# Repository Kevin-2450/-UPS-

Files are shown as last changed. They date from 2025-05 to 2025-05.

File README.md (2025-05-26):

# 内置电池的SK150C桌面电源

#### 介绍
给自己DIY的内置电池的SK150C桌面电源写的固件。

#### 开源硬件
 https://oshwhub.com/kevin1415926/sk150c-expansion-board-four-stri

## 项目简介
本项目是以STM32F030F4P6作为EC，HUSB238作为协议芯片取电，SC8886S作为充电/电源路径管理芯片，以BM3451作为锂电池保护和均压芯片。虽然是作为SK150C的拓展板来设计的，其实实际上达到了一个UPS电源的效果。
V2版本，相较V1硬件软件都有所改动：
* RY9121更换为RY8411；
* 增加散热风扇，散热风扇尺寸为2507，风扇驱动电压为5V；
* 重建3D外壳减小整体尺寸；
* 侧面引出复位按键；
* 电池组不再绑定在PCB上。另外采用了一个4串一并的21700锂电池组，散热和灵活性更加优秀。

## 项目参数和功能

* 左侧两个C口靠后的是充电口，靠前的一个连接到了CH342K，这个芯片的两个串口，分别连接到EC（COM19）和SK150C（COM15）连接到EC的串口可以读取充放电信息以及适配器信息，连接到SK150C的串口可以连接到SK150C的上位机玩；
* 正面的按键是开关，按下之后SK150C会上电并且按键会亮起；
* 本项目固件中自动使用HUSB238向适配器动态申请最高电压，并且根据适配器输入出电流能力设置输入限流；
* 由SC8886S自动完成电源路径动态管理；
* 实测V2版本在有风扇辅助散热的情况下最大充电功率可以达到100W；
* 两个LED实现简单的充电指示，当充电电流>=0.1A的时候左侧LED常亮表示正在充电，当充电电流<0.1A的时候充电截至（即充满）右侧LED常亮；
* 拔出电源适配器的时候系统进入低功耗模式，单片机本身进入stop模式，暂时没有测低功耗模式续航；
* BM3451电池保护芯片对四节电池进行均压和过充过放过流保护；
* 外壳在两个C口边上留了复位按键的小孔，在出现意外的错误的时候可以复位主控。

## 软件代码
代码请移步：
gitee地址：https://gitee.com/Xiao_Hang123/UPS_SC8886S_STM32F030.git
github地址https://github.com/Kevin-2450/-UPS-.git
模型文件一并保存在这个项目中，使用catia画的

## 注意事项

* 电源芯片SC8886和SC8886S不能在这里混用，用SC8886会导致DCDC电路震荡，需要修改RC补偿网络我尝试过几组值但是没有成功.
* PCB上R12是NTC电阻，需要10KB值为3950的热敏电阻，如果不需要温度保护功能则在PCB正面R12的地方焊一个10K的电阻，如果需要温度保护功能则正面的R12留空，背面有NTC电阻的焊盘在那里焊上NTC电阻然后把NTC电阻贴到电池组上；
* 电池刚装上去或者电池拆下来又装上去之后BM3451会进入保护状态，需要先插入STlink给单片机供电然后插入电源适配器进入一下充电状态激活电池组。拔下stlink之后再次插入适配器如果充电指示灯正常亮起那么应该正常激活了

## 组装流程
* PCB装之前需要激活电池（BM3451初始状态时保护的，需要充一下电激活），不建议用另一个可调电源绕过sc8886直接给电池组充电，有概率击穿buck boost电路的MOSFET。
* 先装两个香蕉插头和按钮，然后先把香蕉插头和按钮背面的线先接好，按钮需要先焊线，需要一个单头的XH2.54- 4P的线，原理图上对应的按键接口中，VOUT和PGND连接到按钮的LED两个引脚（注意是有极性的），KEY和AGND连接到按钮的一组常开触点上，按键的插口在靠近输出的那个XT30接口的位置；
* PCB上另一个xh2.54-4P的针座和SK250C背后的串口接口相连，需要xh2.54-4P的同向双头线，长度10cm左右即可
* 接线示意图：




* 风扇应该用四个M2.5的螺丝固定上去，但是手头没有就直接热熔胶打上去了
* 里面的螺母不好上，可以先用热熔胶固定到指定位置然后直接拧上螺丝

## 一些物料购买链接
   购买链接仅供参考
* SK150C本体：【淘宝】7天无理由退货 https://e.tb.cn/h.6ML17TWPs9Xl9DF?tk=FDHNV59dC1k tG-#22>lD 「SK150C彩屏数控升降压可调直流稳压电源恒压恒流充电模块40V8A」
* 香蕉插座：【淘宝】假一赔四 https://e.tb.cn/h.6MMF2UE5su34TOE?tk=g2IlV59WM2k CZ225 「高压安全型4mm孔面板香蕉插座孔电流32a接线柱连接器焊接式」
* 带LED按钮：【淘宝】7天无理由退货 https://e.tb.cn/h.6MMttoUPJefJ3lp?tk=OGdbV592zLV MF287 「12/16/19/22MM超短金属复位按钮 轻触开关带灯超薄微行程电动开关」
这个选12mm 蓝色环形电源灯

## 实物图
串口输出的内容展示
VBUS是输入电压，VSYS是输出电压，VBAT是电池电压IIN是从适配器输入的电流ICHG是电池充电电流，IDCHG是电池放电电流 CMPIN是sc8886S的独立比较器输入电压，没什么关系。
屏幕截图 2025-05-05 172927.png
图1：stm32输出的内容展示

成品展示：







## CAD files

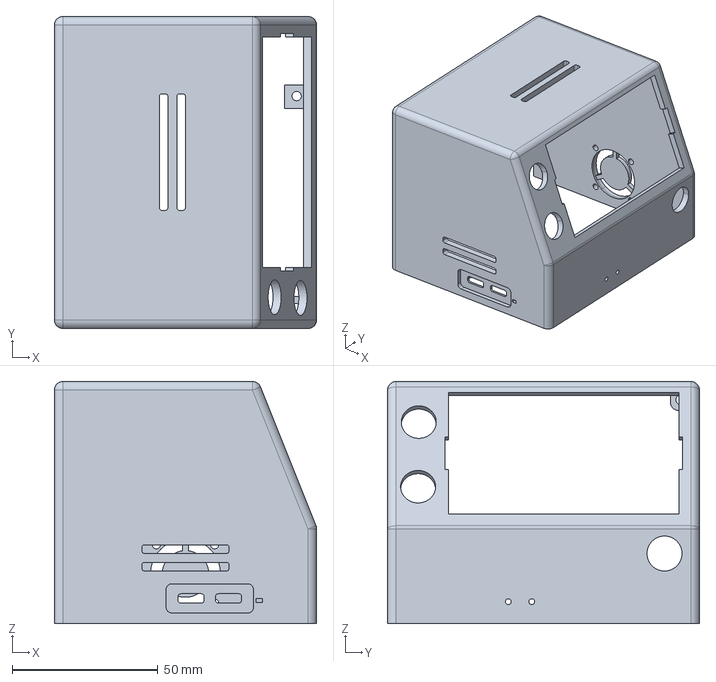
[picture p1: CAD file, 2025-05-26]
models/top.stp
90.0 x 107.0 x 83.0 mm

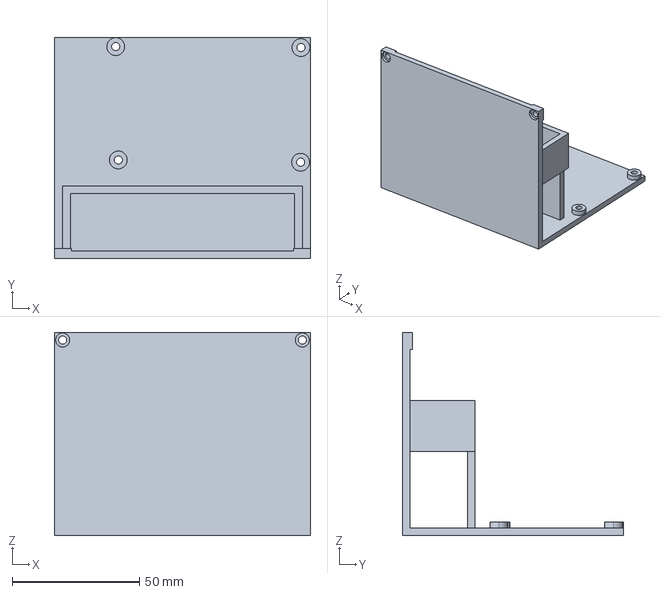
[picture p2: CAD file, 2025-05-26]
models/bottom.stp
100.4 x 86.7 x 79.7 mm

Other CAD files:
models/bottom.gcode.3mf
models/PCB/3D_PCBV2_2025-05-19.CATProduct
models/PCB/COMPOUND.CATPart
models/PCB/COMPOUND_1.CATPart
models/PCB/COMPOUND_10.CATPart
models/PCB/COMPOUND_11.CATPart
models/PCB/COMPOUND_12.CATPart
models/PCB/COMPOUND_13.CATPart
models/PCB/COMPOUND_14.CATPart
models/PCB/COMPOUND_15.CATPart
models/PCB/COMPOUND_2.CATPart
models/PCB/COMPOUND_3.CATPart
models/PCB/COMPOUND_4.CATPart
models/PCB/COMPOUND_5.CATPart
models/PCB/COMPOUND_6.CATPart
models/PCB/COMPOUND_7.CATPart
models/PCB/COMPOUND_8.CATPart
models/PCB/COMPOUND_9.CATPart
models/PCB/CW82-Board.CATPart
models/PCB/CW82-C21-CAP-SMD_BD8.0-L8.3-W8.3-LS9.0-FD.CATPart
models/PCB/CW82-C39-C0603.CATPart
models/PCB/CW82-C41-C0805.CATPart
models/PCB/CW82-Q12-DFN-8_L5.9-W5.2-P1.27-LS6.2-BL.CATPart
models/PCB/CW82-Q14-POWERVDFN-8_L3.2-W3.1-P0.65-LS3.3-BL-1.CATPart
models/PCB/CW82-U15-CONN-TH_XT30U-F.CATPart
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

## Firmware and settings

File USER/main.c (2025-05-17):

#include "stm32f0xx.h"
#include "stm32f0xx_conf.h"

#include "led.h"

#include "tim.h"
#include "key.h" 

#include "isr.h"
#include "delay.h"
#include "uart.h"

#include "husb238.h"
#include "sc8886.h"

void LP_Ctrl(void);

int main(){
    delay_init(SystemCoreClock/1000000);
    UART1_Init(115200);
    
    I2C1_Init();
    LED_Init();
    key_init();
    
    delay_ms(100);
    
    sc8886_init();
    TIM1_Init();
    TIM3_Init();

    printf("init successful @%dMHz\n",SystemCoreClock/1000000);
//    GPIOA->ODR |= 1<<1;
    
    while(1){
        __WFI();    // 主循环等待中断，进入低功耗模式
        LP_Ctrl();
    }
}


void LP_Ctrl(void){
    if(mode == NO_ADAPTER_RUN)
    {
        sc8886_performance_mode_enable();
    }
    else if(mode == STOP)
    {
        sc8886_performance_mode_disable();          // SC8886进入低功耗模式
        LED1_Off();                                 // 关闭LED1
        LED2_Off();
        GPIOA->ODR &= ~(1<<1);

        // 关闭中断
        __disable_irq();
        PWR_EnterSTOPMode(PWR_Regulator_LowPower, PWR_STOPEntry_WFI);
        
        SystemInit();
        RCC_APB1PeriphClockCmd(RCC_APB1Periph_PWR, ENABLE);
        __enable_irq();
        if(CHRG_OK){
            mode = ADAPTER_RUN;
        }
        else mode = NO_ADAPTER_RUN;
    }
}

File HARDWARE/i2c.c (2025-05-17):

#include "i2c.h"

#define I2C_TIMEOUT 600

// I2C1初始化函数
void I2C1_Init(void) {
    GPIO_InitTypeDef GPIO_InitStructure;
    I2C_InitTypeDef I2C_InitStructure;

    // 使能GPIOA和I2C1的时钟
    RCC_AHBPeriphClockCmd(RCC_AHBPeriph_GPIOA, ENABLE);
    RCC_APB1PeriphClockCmd(RCC_APB1Periph_I2C1, ENABLE);

    // 配置PA9 (SCL) 和 PA10 (SDA) 为复用开漏输出
    GPIO_InitStructure.GPIO_Pin = GPIO_Pin_9 | GPIO_Pin_10;
    GPIO_InitStructure.GPIO_Mode = GPIO_Mode_AF;
    GPIO_InitStructure.GPIO_Speed = GPIO_Speed_50MHz;
    GPIO_InitStructure.GPIO_OType = GPIO_OType_OD;
    GPIO_InitStructure.GPIO_PuPd = GPIO_PuPd_UP;
    GPIO_Init(GPIOA, &GPIO_InitStructure);

    // 将PA9和PA10连接到I2C1
    GPIO_PinAFConfig(GPIOA, GPIO_PinSource9, GPIO_AF_4);
    GPIO_PinAFConfig(GPIOA, GPIO_PinSource10, GPIO_AF_4);


	I2C_InitStructure.I2C_Mode = I2C_Mode_I2C;
	I2C_InitStructure.I2C_Ack = I2C_Ack_Enable;	
	I2C_InitStructure.I2C_AcknowledgedAddress = I2C_AcknowledgedAddress_7bit;
	I2C_InitStructure.I2C_DigitalFilter = 0x01;
	I2C_InitStructure.I2C_OwnAddress1=0x00;
	//I2C_InitStructure.I2C_Timing = 0x00201D2B;//100Khz
	I2C_InitStructure.I2C_Timing =0x0010020A;//400Khz
	I2C_InitStructure.I2C_AnalogFilter = I2C_AnalogFilter_Enable;
	
	I2C_Init(I2C1, &I2C_InitStructure);	
	I2C_Cmd(I2C1, ENABLE);
} 



uint8_t  I2C_Read(uint8_t DevAddr, uint8_t RegAddr, uint8_t* pBuffer, uint8_t NumByteToRead)
{  
	uint16_t timeout = I2C_TIMEOUT;
	/* While the bus is busy */
	while(I2C_GetFlagStatus(I2C1, I2C_FLAG_BUSY) != RESET)
	{
		if((timeout--) == 0)
		{
			return 1;
		}
	}
	/* Generate start & wait event detection */
	I2C_TransferHandling(I2C1, (DevAddr<<1), 1, I2C_SoftEnd_Mode, I2C_Generate_Start_Write);
	timeout = I2C_TIMEOUT;
	while (I2C_GetFlagStatus(I2C1, I2C_FLAG_TXIS) == RESET)
	{
		if((timeout--) == 0)
		{   
			return 2;
		}
	}
	I2C_SendData(I2C1, RegAddr);
	timeout = I2C_TIMEOUT;	
	while (I2C_GetFlagStatus(I2C1, I2C_FLAG_TC) == RESET)
	{
		if((timeout--) == 0)
		{
			return 3;
		}
	}
	/* Send STRAT condition a second time */  
	I2C_TransferHandling(I2C1, (DevAddr<<1), NumByteToRead,  I2C_AutoEnd_Mode, I2C_Generate_Start_Read);
	
	/* While there is data to be read */
	while(NumByteToRead)  
	{	
		timeout = I2C_TIMEOUT;
		
		while(I2C_GetFlagStatus(I2C1, I2C_FLAG_RXNE) == RESET)
		{
			if((timeout--) == 0)
			{
				return 4;
			}
		}
		/* Read a byte from the EEPROM */
		*pBuffer = I2C_ReceiveData(I2C1);
		/* Point to the next location where the byte read will be saved */
		pBuffer++; 
		/* Decrement the read bytes counter */
		NumByteToRead--;        
	}
	
	/* Enable Acknowledgement to be ready for another reception */
	timeout = I2C_TIMEOUT;
	while(I2C_GetFlagStatus(I2C1, I2C_FLAG_STOPF) == RESET)
	{
		if((timeout--) == 0)
		{
			return 5;
		}
	}
	return 0;
}



uint8_t  I2C_Write(uint8_t DevAddr, uint8_t RegAddr,uint8_t* pBuffer, uint8_t NumByteToWrite)
{
	uint16_t timeout = I2C_TIMEOUT;
	
	/* While the bus is busy */
	while(I2C_GetFlagStatus(I2C1, I2C_FLAG_BUSY) != RESET)
	{
		if((timeout--) == 0)
		{
			return 1;
		}
	}
	
	/* Send Touch address for write */	
	I2C_TransferHandling(I2C1, (DevAddr<<1), 1, I2C_Reload_Mode, I2C_Generate_Start_Write);
	
	timeout = I2C_TIMEOUT;
	while(I2C_GetFlagStatus(I2C1, I2C_FLAG_TXIS)==RESET)
	{
		if((timeout--) == 0)
		{
			return 2;
		}
	}
	
	I2C_SendData(I2C1, RegAddr);
 
	timeout = I2C_TIMEOUT;
	while(I2C_GetFlagStatus(I2C1, I2C_FLAG_TCR) == RESET)
	{
		if((timeout--) == 0)
		{
			return 3;
		}
	}
	
	I2C_TransferHandling(I2C1, (DevAddr<<1), NumByteToWrite, I2C_AutoEnd_Mode, I2C_No_StartStop);
	
	/* While there is data to be written */
	while(NumByteToWrite--)  
	{
		timeout = I2C_TIMEOUT;
		/* Test on EV8 and clear it */
		while (I2C_GetFlagStatus(I2C1, I2C_FLAG_TXIS) == RESET)
		{
			if((timeout--) == 0)
			{
				return 4;
			}
		}
		/* Send the current byte */
		I2C_SendData(I2C1, *pBuffer); 
 
		/* Point to the next byte to be written */
		pBuffer++; 		
	}
	/* Send STOP condition */
	timeout = I2C_TIMEOUT;
	while(I2C_GetFlagStatus(I2C1, I2C_FLAG_STOPF) == RESET)
	{
		if((timeout--) == 0)
		{
			return 5;
		}
	}
	
	return 0;
	
}

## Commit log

2025-04-28 初始版本，能够完成基本充电、数据读取等操作
2025-04-30 增加了MCU低功耗模式
2025-05-05 优化STOP模式逻辑，优化自动限流逻辑
2025-05-05 增加了十分简单的LED充电指示功能
2025-05-05 加入了3D外壳文件
    [3D_PCB2_2025-05-03.CATProduct, COMPOUND.CATPart, COMPOUND_1.CATPart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]
2025-05-05 更新README
2025-05-06 增加PCB文件
2025-05-17 适配V2版本硬件
2025-05-26 1.更新3D外壳文件 2.更新V2版本PCB文件 3.增加README内容
    [3D_PCB2_2025-05-03.CATProduct, 3D_PCBV2_2025-05-19.CATProduct, COMPOUND.CATPart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]
